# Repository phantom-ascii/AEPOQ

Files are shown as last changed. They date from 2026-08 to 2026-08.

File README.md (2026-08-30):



# AEPOQ
## born to be different

AEPOQ was created by a 14 year old kid. I created AEPOQ to study on keyboard layouts and matricies. "Why" you may ask... Well i want to creat a laptop in the next 2 years and what better way to learn about hardware and laptops than making a keyboard (there are proably alot of better ways.) Unfortunately i could not add my full master step die to githubs large file limit and i didnt have time to set up lfs or smth like that cause im leaving for school in 2 hours. Anyways the keyboard is a 68 key 65% keyboard designed for productivity. It has a rotaty switch and an oled to make it special. AND A CANDY HOLDER ON THE RIGHT.Heres some eye candy:

Screenshot From 2026-08-30 17-38-26
Screenshot From 2026-08-30 16-52-24

Screenshot From 2026-08-30 16-23-58
Screenshot From 2026-08-30 16-23-42
Screenshot From 2026-08-30 16-22-54
Screenshot From 2026-08-29 22-46-02
Screenshot From 2026-08-29 22-43-03
Screenshot From 2026-08-29 22-37-18

 I used a normal mattix for yhe key switches and a raspberry pi pico for the mcu. the firmware is a test and im not expecting it to work. i will fix it once i actually build the keyboard as that is what i usually do. The keyboard case is at a 6.3~ slant for imprived erganomics. Everything was designed me using models as a guide from open source repositorys. This project is also published on the hackclub programn, forge. I will be using cherry mx keyswitches and generic key caps. The rotary endoer is a ec11 from alps. the oled is a generic 0.91 oled 4 pin header and the mcu is a raspberry pi pico. The keyswitch layout is a generic 65% stagered QWERTY for productivity and general erganomics. If you want to rip any models from this repo go ahead. Its open source anyways.

 Here is the BOM:
 # 65% Custom Keyboard - Master Bill of Materials

## 1. Electronics & Hardware (AliExpress)

| Component | Store | Spec / Description | Price (USD) | Order Link |
| :--- | :--- | :--- | :--- | :--- |
| **Microcontroller** | WeAct Studio Official Store | RP2040 (8MB Black Edition) | $5.16 | [RP2040 Pico Board](https://www.aliexpress.com/item/1005003708090298.html) |
| **Diodes** | Chinese Super Electronic market | 1N4148 SOD-123 SMD Diodes (1000-pack) | $4.54 | [1N4148 SOD-123 Diodes](https://www.aliexpress.com/item/32354597825.html) |
| **Rotary Encoder** | DQLZV Official Store | EC11 Encoder 20mm Half-Handle (5-pack) | $2.85 | [EC11 Rotary Encoder](https://www.aliexpress.com/w/wholesale-digital-encoder-ec11.html) |
| **OLED Display** | diymore Alice1101983 Store | 0.91" 128x32 I2C Display Module | $3.09 | [0.91" I2C OLED Module](https://www.aliexpress.com/item/32815893431.html) |
| **Switches** | The Powerpuff Girls Switch Store | Cherry Switches (70-pack) | $26.58 | [Cherry MX Switches](https://www.aliexpress.com/item/100504669940336.html) |
| **Stabilizers** | YMDK Store | Screw-In PCB Mount Stabilizer Set | $18.62 | [YMDK PCB Stabilizers](https://www.aliexpress.com/item/1005012115758953.html) |
| **Keycaps** | Melokey Store | Line Gradient Side-Shine Cherry PBT | $18.32 | [Side-Shine PBT Keycaps](https://www.aliexpress.com/w/wholesale-keycaps-65.html) |
| **Heat-Set Inserts** | Zenhosit Store | Brass Threaded Inserts M2/M2.5/M3 (220-pack) | $4.91 | [M2 Brass Inserts](https://www.aliexpress.com/item/1005010241559236.html) |
| **Choice Discount** | Choice Discounts | Applied Checkout Savings | -$7.07 | — |
| **AliExpress Shipping** | Choice / Standard | Expedited Combined Delivery | $0.00 | Free |
| **AliExpress Subtotal** | | | **$84.06** | |

---

## 2. PCB Fabrication & 3D Printing (JLCPCB / JLC3DP)

| Item | Service | Description | Price (USD) |
| :--- | :--- | :--- | :--- |
| **PCB Prototypes (`Aepoq_Y7`)** | JLCPCB | White Solder Mask, 1.6 mm, HASL (5-pack) | $22.60 |
| **Keyboard Case (`Case.step`)** | JLC3DP | 9600 Resin, White SLA 3D Print (1 pc) | $88.74 |
| **Keyboard Lid (`Lid.step`)** | JLC3DP | 9600 Resin, White SLA 3D Print (1 pc) | $13.04 |
| **JLCPCB Shipping** | Standard / Express | Package Weight: 3.01 kg | $90.06 |
| **JLCPCB Coupons** | Checkout Coupon | Applied Savings | -$25.00 |
| **JLCPCB Subtotal** | | | **$189.44** |

---

## 3. Total Project Cost

| Category | Amount (USD) |
| :--- | :--- |
| **AliExpress Subtotal** | $84.06 |
| **JLCPCB Subtotal** | $189.44 |
| **Grand Total** | **$273.50** |

the whole build comes out to around $273, with jlcpcb taking up $189 of that. the shipping and case prices ended up pretty high because i intentionally went with a filled interior instead of hollowing it out. i've always hated light, cheap-feeling keyboards, so i wanted this build to have some serious weight to it and feel super solid on the desk even if it meant paying extra for the resin.




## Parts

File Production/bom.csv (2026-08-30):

Designator | Footprint | Quantity | Value | LCSC Part #
A1 | Raspberry_Pi_Pico | 1 | RaspberryPi_Pico
D1, D10, D11, D12, D13, D14, D15, D16, D17, D18, D19, D2, D20, D21, D22, D23, D24, D25, D26, D27, D28, D29, D3, D30, D31, D32, D33, D34, D35, D36, D37, D38, D39, D4, D40, D41, D42, D44, D45, D46, D47, D48, D49, D5, D50, D51, D52, D53, D54, D55, D56, D58, D59, D6, D60, D61, D62, D63, D66, D7, D70, D71, D72, D73, D74, D75, D8, D9 | D_DO-35_SOD27_P7.62mm_Horizontal | 68 | 1N4148
SW1, SW10, SW11, SW12, SW13, SW14, SW15, SW16, SW17, SW18, SW19, SW2, SW20, SW21, SW22, SW23, SW24, SW25, SW26, SW27, SW28, SW29, SW3, SW30, SW31, SW32, SW33, SW34, SW35, SW36, SW37, SW38, SW39, SW4, SW40, SW41, SW42, SW44, SW45, SW46, SW47, SW48, SW49, SW5, SW50, SW51, SW52, SW53, SW54, SW55, SW56, SW58, SW59, SW6, SW60, SW61, SW62, SW63, SW66, SW7, SW70, SW71, SW72, SW73, SW74, SW75, SW8, SW9 | SW_MX_1u | 68 | MX_SW_solder
SW43 | RotaryEncoder_Alps_EC11E-Switch_Vertical_H20mm | 1 | RotaryEncoder_Switch
U1 | ER_OLEDM0.91_1x-I2C | 1 | ER_OLEDM0.91_1x-I2C

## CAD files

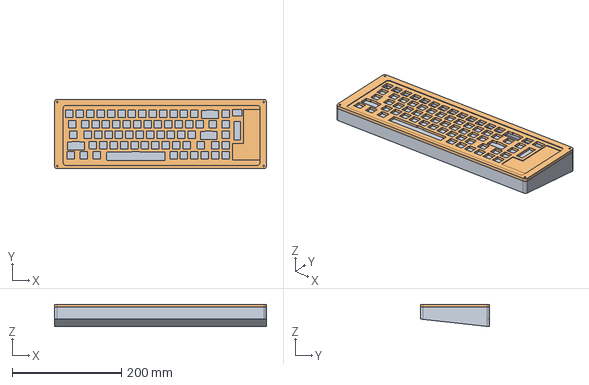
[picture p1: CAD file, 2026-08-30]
CAD/Master.FCStd
388.0 x 127.0 x 41.0 mm
Case
Lid

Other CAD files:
CAD/Lid.step
CAD/Case.step
CAD/pcb.step

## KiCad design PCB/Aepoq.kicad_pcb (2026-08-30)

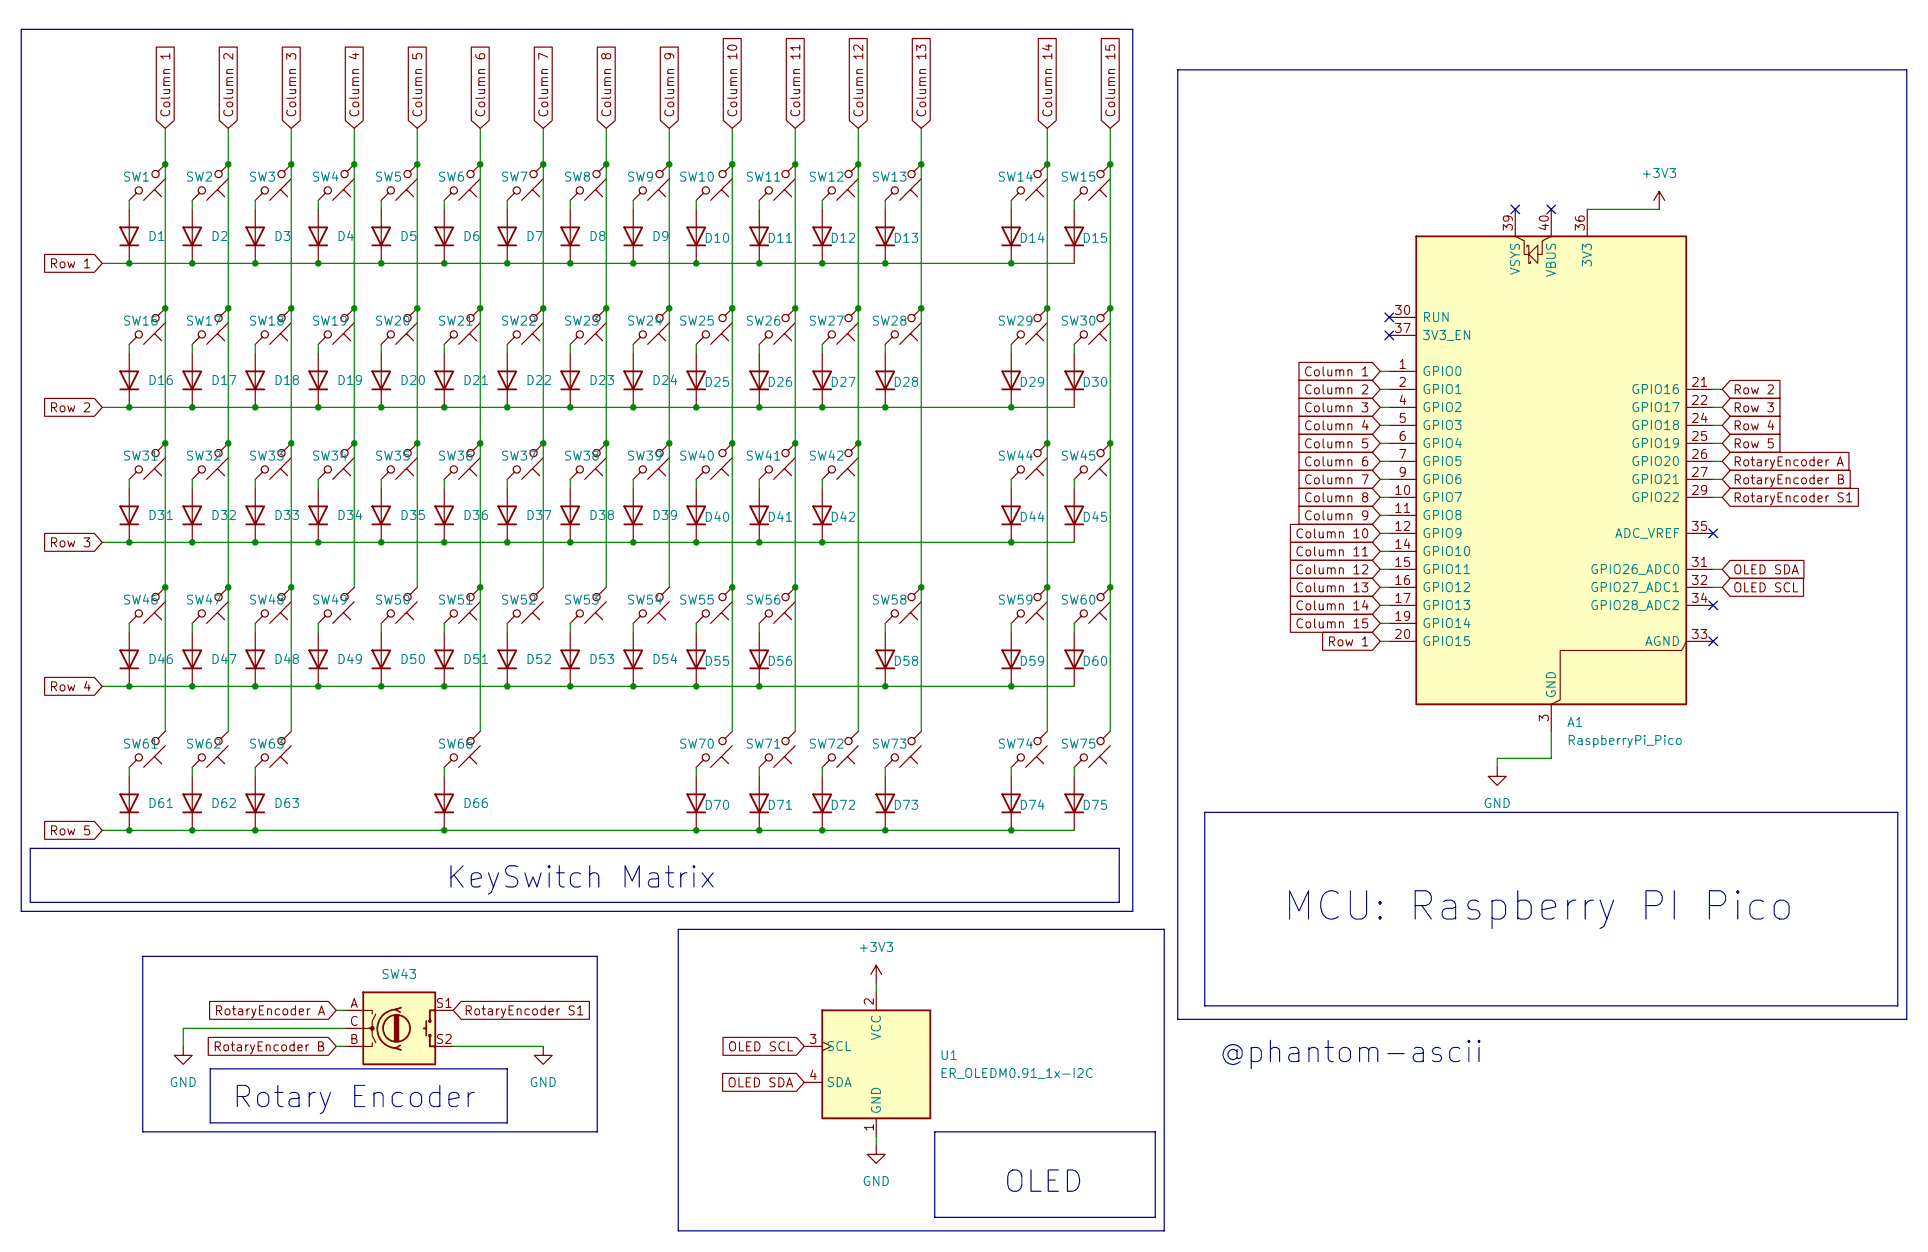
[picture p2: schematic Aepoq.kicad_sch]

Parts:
A1: RaspberryPi_Pico; Raspberry_Pi_Pico
D1, D2, D3, D4, D5, D6, D7, D8, D9, D10, D11, D12, D13, D14, D15, D16, D17, D18, D19, D20, D21, D22, D23, D24, D25, D26, D27, D28, D29, D30, D31, D32, D33, D34, D35, D36, D37, D38, D39, D40, D41, D42, D44, D45, D46, D47, D48, D49, D50, D51, D52, D53, D54, D55, D56, D58, D59, D60, D61, D62, D63, D66, D70, D71, D72, D73, D74, D75: 1N4148; D_DO-35_SOD27_P7.62mm_Horizontal
SW1, SW2, SW3, SW4, SW5, SW6, SW7, SW8, SW9, SW10, SW11, SW12, SW13, SW14, SW15, SW16, SW17, SW18, SW19, SW20, SW21, SW22, SW23, SW24, SW25, SW26, SW27, SW28, SW29, SW30, SW31, SW32, SW33, SW34, SW35, SW36, SW37, SW38, SW39, SW40, SW41, SW42, SW44, SW45, SW46, SW47, SW48, SW49, SW50, SW51, SW52, SW53, SW54, SW55, SW56, SW58, SW59, SW60, SW61, SW62, SW63, SW66, SW70, SW71, SW72, SW73, SW74, SW75: MX_SW_solder; SW_MX_1u
SW43: RotaryEncoder_Switch; RotaryEncoder_Alps_EC11E-Switch_Vertical_H20mm
U1: ER_OLEDM0.91_1x-I2C

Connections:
+3V3: A1.36 (3V3), U1.2 (VCC)
Column 1: A1.1 (GPIO0), SW1.1, SW16.1, SW31.1, SW46.1, SW61.1
Column 2: A1.2 (GPIO1), SW2.1, SW17.1, SW32.1, SW47.1, SW62.1
Column 3: A1.4 (GPIO2), SW3.1, SW18.1, SW33.1, SW48.1, SW63.1
Column 4: A1.5 (GPIO3), SW4.1, SW19.1, SW34.1, SW49.1
Column 5: A1.6 (GPIO4), SW5.1, SW20.1, SW35.1, SW50.1
Column 6: A1.7 (GPIO5), SW6.1, SW21.1, SW36.1, SW51.1, SW66.1
Column 7: A1.9 (GPIO6), SW7.1, SW22.1, SW37.1, SW52.1
Column 8: A1.10 (GPIO7), SW8.1, SW23.1, SW38.1, SW53.1
Column 9: A1.11 (GPIO8), SW9.1, SW24.1, SW39.1, SW54.1
Column 10: A1.12 (GPIO9), SW10.1, SW25.1, SW40.1, SW55.1, SW70.1
Column 11: A1.14 (GPIO10), SW11.1, SW26.1, SW41.1, SW56.1, SW71.1
Column 12: A1.15 (GPIO11), SW12.1, SW27.1, SW42.1, SW72.1
Column 13: A1.16 (GPIO12), SW13.1, SW28.1, SW58.1, SW73.1
Column 14: A1.17 (GPIO13), SW14.1, SW29.1, SW44.1, SW59.1, SW74.1
Column 15: A1.19 (GPIO14), SW15.1, SW30.1, SW45.1, SW60.1, SW75.1
GND: A1.3 (GND), A1.8 (GND), A1.13 (GND), A1.18 (GND), A1.23 (GND), A1.28 (GND), A1.38 (GND), SW43.C, SW43.S2, U1.1 (GND)
unnamed: D1.2 (A), SW1.2
unnamed: D2.2 (A), SW2.2
unnamed: D3.2 (A), SW3.2
unnamed: D4.2 (A), SW4.2
unnamed: D5.2 (A), SW5.2
unnamed: D6.2 (A), SW6.2
unnamed: D7.2 (A), SW7.2
unnamed: D8.2 (A), SW8.2
unnamed: D9.2 (A), SW9.2
unnamed: D10.2 (A), SW10.2
unnamed: D11.2 (A), SW11.2
unnamed: D12.2 (A), SW12.2
unnamed: D13.2 (A), SW13.2
unnamed: D14.2 (A), SW14.2
unnamed: D15.2 (A), SW15.2
unnamed: D16.2 (A), SW16.2
unnamed: D17.2 (A), SW17.2
unnamed: D18.2 (A), SW18.2
unnamed: D19.2 (A), SW19.2
unnamed: D20.2 (A), SW20.2
unnamed: D21.2 (A), SW21.2
unnamed: D22.2 (A), SW22.2
unnamed: D23.2 (A), SW23.2
unnamed: D24.2 (A), SW24.2
unnamed: D25.2 (A), SW25.2
unnamed: D26.2 (A), SW26.2
unnamed: D27.2 (A), SW27.2
unnamed: D28.2 (A), SW28.2
unnamed: D29.2 (A), SW29.2
unnamed: D30.2 (A), SW30.2
unnamed: D31.2 (A), SW31.2
unnamed: D32.2 (A), SW32.2
unnamed: D33.2 (A), SW33.2
unnamed: D34.2 (A), SW34.2
unnamed: D35.2 (A), SW35.2
unnamed: D36.2 (A), SW36.2
unnamed: D37.2 (A), SW37.2
unnamed: D38.2 (A), SW38.2
unnamed: D39.2 (A), SW39.2
unnamed: D40.2 (A), SW40.2
unnamed: D41.2 (A), SW41.2
unnamed: D42.2 (A), SW42.2
unnamed: D44.2 (A), SW44.2
unnamed: D45.2 (A), SW45.2
unnamed: D46.2 (A), SW46.2
unnamed: D47.2 (A), SW47.2
unnamed: D48.2 (A), SW48.2
unnamed: D49.2 (A), SW49.2
unnamed: D50.2 (A), SW50.2
unnamed: D51.2 (A), SW51.2
unnamed: D52.2 (A), SW52.2
unnamed: D53.2 (A), SW53.2
unnamed: D54.2 (A), SW54.2
unnamed: D55.2 (A), SW55.2
unnamed: D56.2 (A), SW56.2
unnamed: D58.2 (A), SW58.2
unnamed: D59.2 (A), SW59.2
unnamed: D60.2 (A), SW60.2
unnamed: D61.2 (A), SW61.2
unnamed: D62.2 (A), SW62.2
unnamed: D63.2 (A), SW63.2
unnamed: D66.2 (A), SW66.2
unnamed: D70.2 (A), SW70.2
unnamed: D71.2 (A), SW71.2
unnamed: D72.2 (A), SW72.2
unnamed: D73.2 (A), SW73.2
unnamed: D74.2 (A), SW74.2
unnamed: D75.2 (A), SW75.2
OLED SCL: A1.32 (GPIO27_ADC1), U1.3 (SCL)
OLED SDA: A1.31 (GPIO26_ADC0), U1.4 (SDA)
RotaryEncoder A: A1.26 (GPIO20), SW43.A
RotaryEncoder B: A1.27 (GPIO21), SW43.B
RotaryEncoder S1: A1.29 (GPIO22), SW43.S1
Row 1: A1.20 (GPIO15), D1.1 (K), D2.1 (K), D3.1 (K), D4.1 (K), D5.1 (K), D6.1 (K), D7.1 (K), D8.1 (K), D9.1 (K), D10.1 (K), D11.1 (K), D12.1 (K), D13.1 (K), D14.1 (K), D15.1 (K)
Row 2: A1.21 (GPIO16), D16.1 (K), D17.1 (K), D18.1 (K), D19.1 (K), D20.1 (K), D21.1 (K), D22.1 (K), D23.1 (K), D24.1 (K), D25.1 (K), D26.1 (K), D27.1 (K), D28.1 (K), D29.1 (K), D30.1 (K)
Row 3: A1.22 (GPIO17), D31.1 (K), D32.1 (K), D33.1 (K), D34.1 (K), D35.1 (K), D36.1 (K), D37.1 (K), D38.1 (K), D39.1 (K), D40.1 (K), D41.1 (K), D42.1 (K), D44.1 (K), D45.1 (K)
Row 4: A1.24 (GPIO18), D46.1 (K), D47.1 (K), D48.1 (K), D49.1 (K), D50.1 (K), D51.1 (K), D52.1 (K), D53.1 (K), D54.1 (K), D55.1 (K), D56.1 (K), D58.1 (K), D59.1 (K), D60.1 (K)
Row 5: A1.25 (GPIO19), D61.1 (K), D62.1 (K), D63.1 (K), D66.1 (K), D70.1 (K), D71.1 (K), D72.1 (K), D73.1 (K), D74.1 (K), D75.1 (K)

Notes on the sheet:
Rotary Encoder
OLED
MCU: Raspberry PI Pico
@phantom-ascii
KeySwitch Matrix

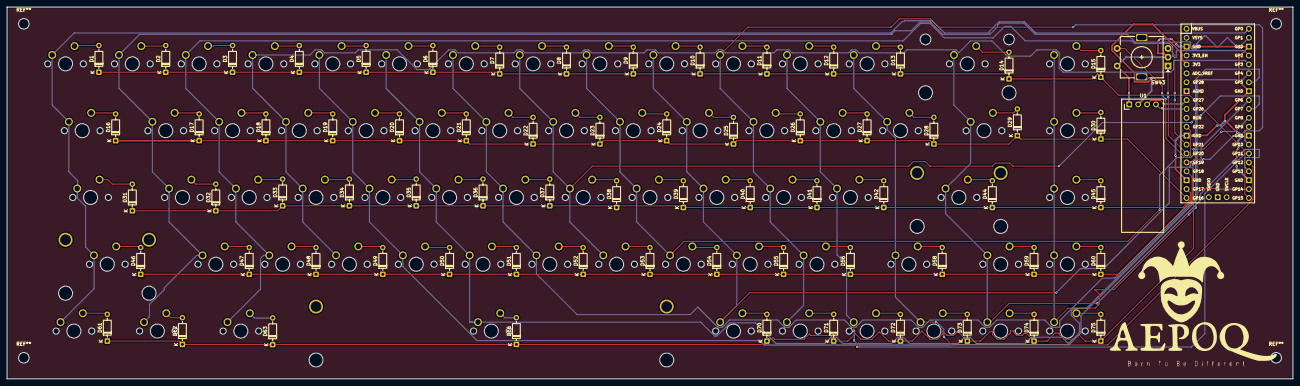
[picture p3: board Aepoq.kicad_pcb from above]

Board: 2 copper layers, 366.7 x 106.0 mm, 139 parts (1 on the bottom side), 95 nets.

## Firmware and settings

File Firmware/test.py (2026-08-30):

import board
import busio
import displayio
import terminalio
from adafruit_display_text import label
import adafruit_ssd1306

from kmk.kmk_keyboard import KMKKeyboard
from kmk.keys import KC
from kmk.scanners import DiodeOrientation
from kmk.modules.encoder import EncoderHandler
from kmk.extensions.media_keys import MediaKeys

keyboard = KMKKeyboard()

keyboard.col_pins = (
    board.GP0,  # Col 1
    board.GP1,  # Col 2
    board.GP2,  # Col 3
    board.GP3,  # Col 4
    board.GP4,  # Col 5
    board.GP5,  # Col 6
    board.GP6,  # Col 7
    board.GP7,  # Col 8
    board.GP8,  # Col 9
    board.GP9,  # Col 10
    board.GP10, # Col 11
    board.GP11, # Col 12
    board.GP12, # Col 13
    board.GP13, # Col 14
    board.GP14, # Col 15
)

keyboard.row_pins = (
    board.GP15, # Row 1
    board.GP16, # Row 2
    board.GP17, # Row 3
    board.GP18, # Row 4
    board.GP19, # Row 5
)

keyboard.diode_orientation = DiodeOrientation.COL2ROW


media_keys = MediaKeys()
keyboard.extensions.append(media_keys)

displayio.release_displays()
i2c = busio.I2C(scl=board.GP27, sda=board.GP26)
display_bus = displayio.I2CDisplay(i2c, device_address=0x3C)
display = adafruit_ssd1306.SSD1306_I2C(128, 32, i2c)

volume_level = 50  
is_muted = False

def update_oled():
    display.fill(0)
    if is_muted:
        text = "  [ MUTED ]"
        bar = "----------------"
    else:
        text = f" Volume: {volume_level}%"
        bars_filled = int((volume_level / 100) * 14)
        bar = "[" + "=" * bars_filled + " " * (14 - bars_filled) + "]"

    display.text("=== 65% KEYBOARD ===", 0, 0, 1)
    display.text(text, 0, 12, 1)
    display.text(bar, 0, 24, 1)
    display.show()
update_oled()


def volume_up(state):
    global volume_level, is_muted
    is_muted = False
    volume_level = min(100, volume_level + 5)
    keyboard.tap_key(KC.AUDIO_VOL_UP)
    update_oled()

def volume_down(state):
    global volume_level, is_muted
    is_muted = False
    volume_level = max(0, volume_level - 5)
    keyboard.tap_key(KC.AUDIO_VOL_DOWN)
    update_oled()

def toggle_mute(state):
    global is_muted
    is_muted = not is_muted
    keyboard.tap_key(KC.AUDIO_MUTE)
    update_oled()

encoder_handler = EncoderHandler()
encoder_handler.pins = ((board.GP20, board.GP21, board.GP22, False),)
encoder_handler.map = [
    ((volume_up, volume_down, toggle_mute),),
]
keyboard.modules.append(encoder_handler)

keyboard.keymap = [
    [
        # Row 1 (Esc to Ins)
        KC.ESC,  KC.N1,   KC.N2,   KC.N3,   KC.N4,   KC.N5,   KC.N6,   KC.N7,   KC.N8,   KC.N9,   KC.N0,   KC.MINS, KC.EQL,  KC.BSPC, KC.INS,
        # Row 2 (Tab to Del)
        KC.TAB,  KC.Q,    KC.W,    KC.E,    KC.R,    KC.T,    KC.Y,    KC.U,    KC.I,    KC.O,    KC.P,    KC.LBRC, KC.RBRC, KC.BSLS, KC.DEL,
        # Row 3 (Caps to PgUp)
        KC.CAPS, KC.A,    KC.S,    KC.D,    KC.F,    KC.G,    KC.H,    KC.J,    KC.K,    KC.L,    KC.SCLN, KC.QUOT, KC.ENT,  KC.PGUP,
        # Row 4 (Shift to PgDn)
        KC.LSFT, KC.Z,    KC.X,    KC.C,    KC.V,    KC.B,    KC.N,    KC.M,    KC.COMM, KC.DOT,  KC.SLSH, KC.RSFT, KC.UP,   KC.PGDN,
        # Row 5 (Ctrl to Right)
        KC.LCTL, KC.LGUI, KC.LALT,                   KC.SPC,                    KC.RALT, KC.FN,   KC.RCTL, KC.LEFT, KC.DOWN, KC.RGHT,
    ]
]

if __name__ == "__main__":
    keyboard.go()

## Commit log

2026-08-30 Adding all files
    [Aepoq.kicad_pcb, Aepoq.kicad_sch, Case.step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]
2026-08-30 FIX FILES
    [Case.step, Lid.step, pcb.step]
2026-08-30 Enhance README with project details and BOM
    Expanded the README to include detailed project information, BOM, and images of the custom keyboard design.
2026-08-30 Update README with build cost and material choices
    Added details about the total cost of the build and the reasoning behind the choice of materials for a solid feel.
